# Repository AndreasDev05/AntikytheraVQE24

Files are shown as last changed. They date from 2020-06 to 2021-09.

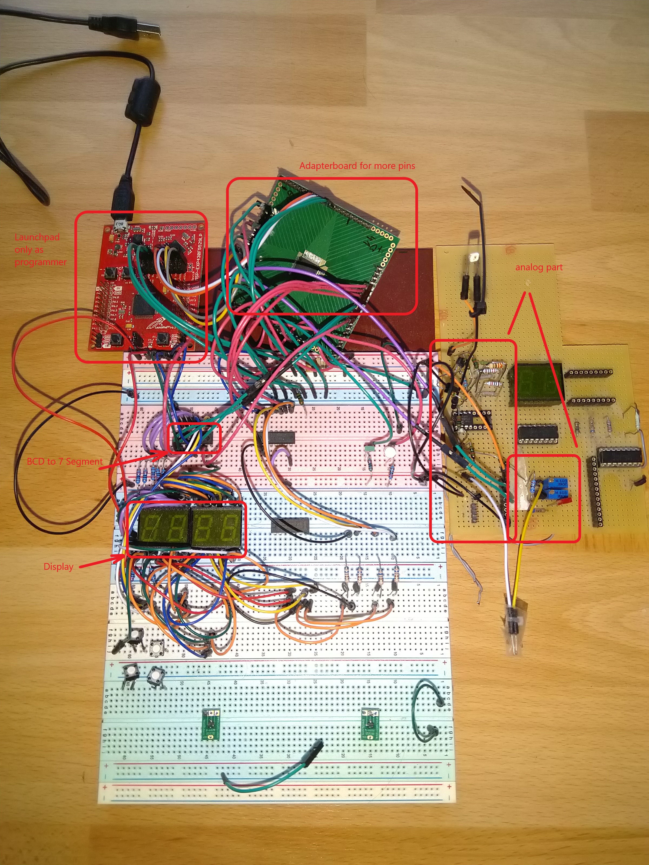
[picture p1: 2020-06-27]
Photos/Steckboard_202006.jpg

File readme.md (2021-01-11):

# Einleitung

Eine eigene Uhr zu bauen war ein Vorhaben das ich seit 35 Jahre habe. Damals bekam ich Anzeigen (VQE24) und einen entsprechenden Mikrocontroller geschenkt. Dieser war 2. Wahl und funktionierte auch nicht richtig. Ich bin nie über einen fliegenden Aufbau hinaus gekommen. Das möchte ich jetzt ändern und die Welt auch noch damit "bereichern". Bitte habe Geduld, vieles was ich hier tue, mache zum ersten Mal :wink: .

# Projektstatus:
**Software**

:construction: :construction_worker:

**Hardware (PCB)**

Die Entwicklung der Leiterplatte ist erst einmal fertig, ich habe die "Produktion" beauftragt :relaxed:.

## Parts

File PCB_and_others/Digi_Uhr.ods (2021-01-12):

Pos | Anzahl | Name | Wert | Gehäuse | SMD-Gehäuse
1 | 1 | AL1 | AL-16P01 | D18R7,62 | NO
2 | 1 | D400 | BAS16 | SOT23/3 | YES
3 | 5 | T500, T505, T506, T507, T401 | BSS138G | SOT-23/3 | YES
4 | 5 | T1, T501, T502, T503, T504 | BSS83P | SOT23/3 | YES
5 | 1 | K8 | Connector Power | Stiftleiste_1x03_G_2,54 | NO
6 | 1 | K3 | Connector Programmer | Stiftleiste_1x09_G_2,54 | NO
7 | 1 | RE400 | DIP 9051-D 5V | DIP_LOW_W/O | NO
8 | 1 | K300 | Einlöt-DC-Buchse 5.5/2.1mm | EINLÖT-DC-BUCHSE_2.5MM | NO
9 | 1 | T300 | IRFD9120 | DIL4 | NO
10 | 2 | J1, R500 | 0-OHM | 0603 | YES
11 | 1 | R2 | 1,4K | 0603 | YES
12 | 6 | R509, R510, R511, R512, R513, R530 | 10 | 0603 | YES
13 | 5 | R401, R406, R409, R419, R420, R302 | 100k | 0603 | YES
14 | 6 | C2, C13, C400, C402, C405, C410 | 100nF | 0603 | YES
15 | 6 | C4, C306, C401, C403, C509, C510 | 100nF | 1206 | YES
16 | 3 | C302, C303, C304 | 100µF | 2817_ELKO | YES
17 | 3 | R11, R422, R408 | 10K | 1206 | YES
18 | 1 | R405 | 10K | VISHAY_64W | NO
19 | 15 | R407, R411, R412, R413, R414, R415, R416, R505, R506, R507, R508, R514, R515, R516, R517 | 10k | 0603 | YES
20 | 9 | C406, C407, C409, C504, C505, C506, C507, C508, C511 | 10nF | 0603 | YES
21 | 2 | C14, C15 | 10pF | 0603 | YES
22 | 2 | C3, C12 | 10µF | 2412_ELKO | YES
23 | 1 | C301 | 10µF | 0805 | YES
24 | 1 | R300 | 19K1 | 0603 | YES
25 | 1 | R410 | 1k | 1206 | YES
26 | 1 | R4 | 1M | 0603 | YES
27 | 2 | C11, C408 | 1nF | 0603 | YES
28 | 5 | L300, L301, L302, L303, L304 | 1µH | Chip_Coil_4026 | YES
29 | 1 | L305 | 1µH | 1206-D | YES
30 | 1 | C305 | 2,2µF | 0805 | YES
31 | 1 | R520 | 220 | 1206 | YES
32 | 3 | C7, C8, C404 | 220nF | 0603 | YES
33 | 2 | C5, C6 | 22pF | 0603 | YES
34 | 5 | L500, L501, L502, L503, L504 | 22µH | SRN4018 Spule | YES
35 | 2 | R5, R6 | 27 | 0603 | YES
36 | 1 | Q1 | 32,768KHz | CFPX-6,7 | YES
37 | 9 | R3, R7, R8, R9, R10, R501, R502, R503, R504 | 33 | 1206 | YES
38 | 3 | R417, R418, R421 | 3M3 | 0805 | YES
39 | 2 | C1, C300 | 470nF | 0603 | YES
40 | 4 | C500, C501, C502, C503 | 470nF | 1206 | YES
41 | 1 | R1 | 47K | 0603 | YES
42 | 2 | R304, R404 | 4k7 | 0603 | YES
43 | 1 | R402 | 4M7 | 0603 | YES
44 | 1 | Q2 | 4MHz | HC49/US | NO
45 | 1 | R303 | 56K | 0603 | YES
46 | 2 | C9, C10 | 56pF | 0603 | YES
47 | 1 | R301 | 60K4 | 0603 | YES
48 | 1 | R400 | 68 | 0603 | YES
49 | 1 | IC2 | 74LS04 | SO14 | YES
50 | 11 | R518, R519, R521, R522, R523, R524, R525, R526, R527, R528, R529 | 82 | 1206 | YES
51 | 1 | R403 | 820k | 0603 | YES
52 | 1 | K1 | A-USBS-B | Assmann_A-USBS-B | NO
53 | 1 | K504 | K2X17_Buchse | 2X17_BUCHSE | NO
54 | 1 | D304 | LED_GRUEN | 0805-D | YES
55 | 2 | D500, D501 | LED_GRUEN_3MM | LED_3MM_GRÜN | NO
56 | 1 | D502 | LED_GRUEN_rechtek | LED_2X5_Grün | NO
57 | 2 | D302, D303 | LED_ROT | 0603-D | YES
58 | 1 | IC402 | LM334Z | TO92(1) | NO
59 | 1 | IC403 | LM4041DIM3-1.2 | SOT23/3 | YES
60 | 1 | IC404 | LP2951 CS33 | SO8_SOT96-1 | YES
61 | 1 | U300 | MAX17620ATA+ | 21-0168E_T822-3_MXM | NO
62 | 1 | IC400, IC405 | MCP602-I/SN | SO8_SOT96-1 | YES
63 | 1 | IC1 | MSP430F5529 | LQFP80_SOT315-1 | YES
64 | 1 | D1 | PRTR5V0U2X | SOT143B | YES
65 | 1 | IC401 | PT100 | STIFTLEISTE_1X02_G_2,54 | NO
66 | 1 | T400 | SFH320-3 | STIFTLEISTE_1X02_G_2,54 | NO
67 | 2 | D300, D301 | SKL13B | DO-214AA(SMB) | YES
68 | 1 | D503 | SMD 0805 gelb | 0805-D | YES
69 | 1 | IC500 | SN7447N | DIL16 | NO
70 | 1 | IC501 | SN74LS47 | SO16 | YES
71 | 1 | X300 | Stützbatterie | BATTERIE_HALTER_VERT | NO
72 | 1 | SW504 | Switch center | 1.14.100.501/0000_RAF (ANDI) | NO
73 | 1 | SW500 | Switch down | 1.14.100.501/0000_RAF (ANDI) | NO
74 | 1 | SW502 | Switch left | 1.14.100.501/0000_RAF (ANDI) | NO
75 | 1 | SW503 | Switch rigth | 1.14.100.501/0000_RAF (ANDI) | NO
76 | 1 | SW501 | Switch up | 1.14.100.501/0000_RAF (ANDI) | NO
77 | 1 | S505 | Taster_Kurzhub | STIFTLEISTE_1X02_G_2,54 | NO
78 | 2 | Display500, Display501 | TLG325 | DX52-11 | NO
79 | 1 | K2 | Verbinder Frontplatte | Stiftleiste_2x17_G_2,54 | NO
 | 178

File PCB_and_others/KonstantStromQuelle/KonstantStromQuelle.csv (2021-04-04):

Reference | Quantity | Value | Footprint | Datasheet
C1 C2 | 2 | 120n | Capacitor_SMD:C_0805_2012Metric_Pad1.15x1.40mm_HandSolder | ~
J1 | 1 | Konstantstromquelle | Package_TO_SOT_THT:TO-92L_Inline_Wide | ~
J2 | 1 | +5V | Connector_Pin:Pin_D0.9mm_L10.0mm_W2.4mm_FlatFork | ~
J3 | 1 | Halte-Pin | Connector_Pin:Pin_D0.9mm_L10.0mm_W2.4mm_FlatFork | ~
Q1 | 1 | BSS138 | Package_TO_SOT_SMD:SOT-23 | https://www.fairchildsemi.com/datasheets/BS/BSS138.pdf
R1 | 1 | 10k Reserve | Resistor_SMD:R_1206_3216Metric_Pad1.42x1.75mm_HandSolder | ~
R2 | 1 | 10k | Resistor_SMD:R_1206_3216Metric_Pad1.42x1.75mm_HandSolder | ~
R3 | 1 | 1k | Resistor_SMD:R_1206_3216Metric_Pad1.42x1.75mm_HandSolder | ~
RV1 | 1 | 10k | Potentiometer_THT:Potentiometer_Bourns_3296W_Vertical | ~
U1 | 1 | LM4041DIM3-1.2 | Package_TO_SOT_SMD:SOT-23 | http://www.ti.com/lit/ds/symlink/lm4041-n.pdf
U2 | 1 | SGM8521 | Package_SO:SO-8_3.9x4.9mm_P1.27mm | I:\User_Daten\andi_dir\Dokumente\Technik\Digi-Uhr\SGM8521.pdf

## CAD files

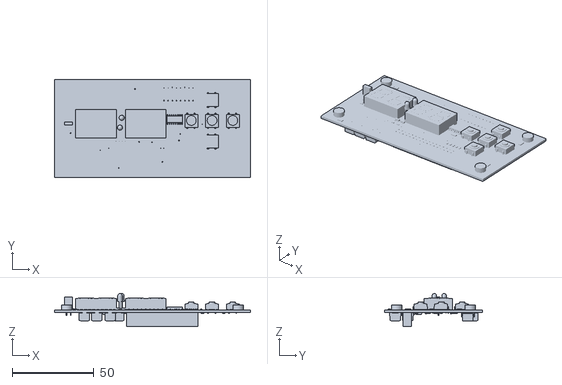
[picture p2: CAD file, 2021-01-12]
PCB_and_others/Digi_Uhr_Front.OBJ
120.0 x 60.0 x 20.2

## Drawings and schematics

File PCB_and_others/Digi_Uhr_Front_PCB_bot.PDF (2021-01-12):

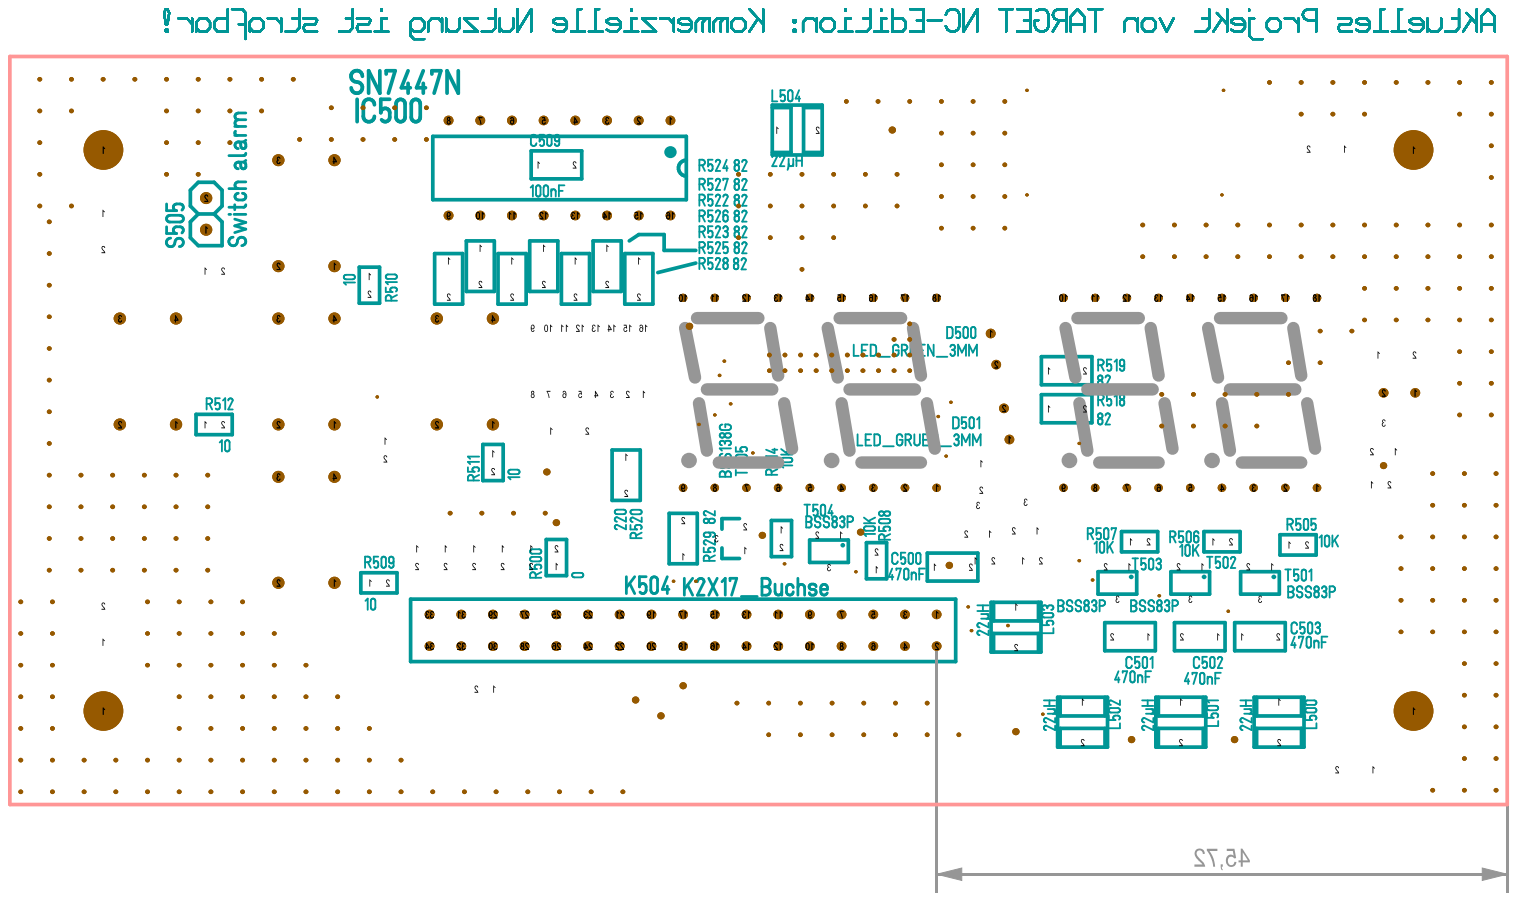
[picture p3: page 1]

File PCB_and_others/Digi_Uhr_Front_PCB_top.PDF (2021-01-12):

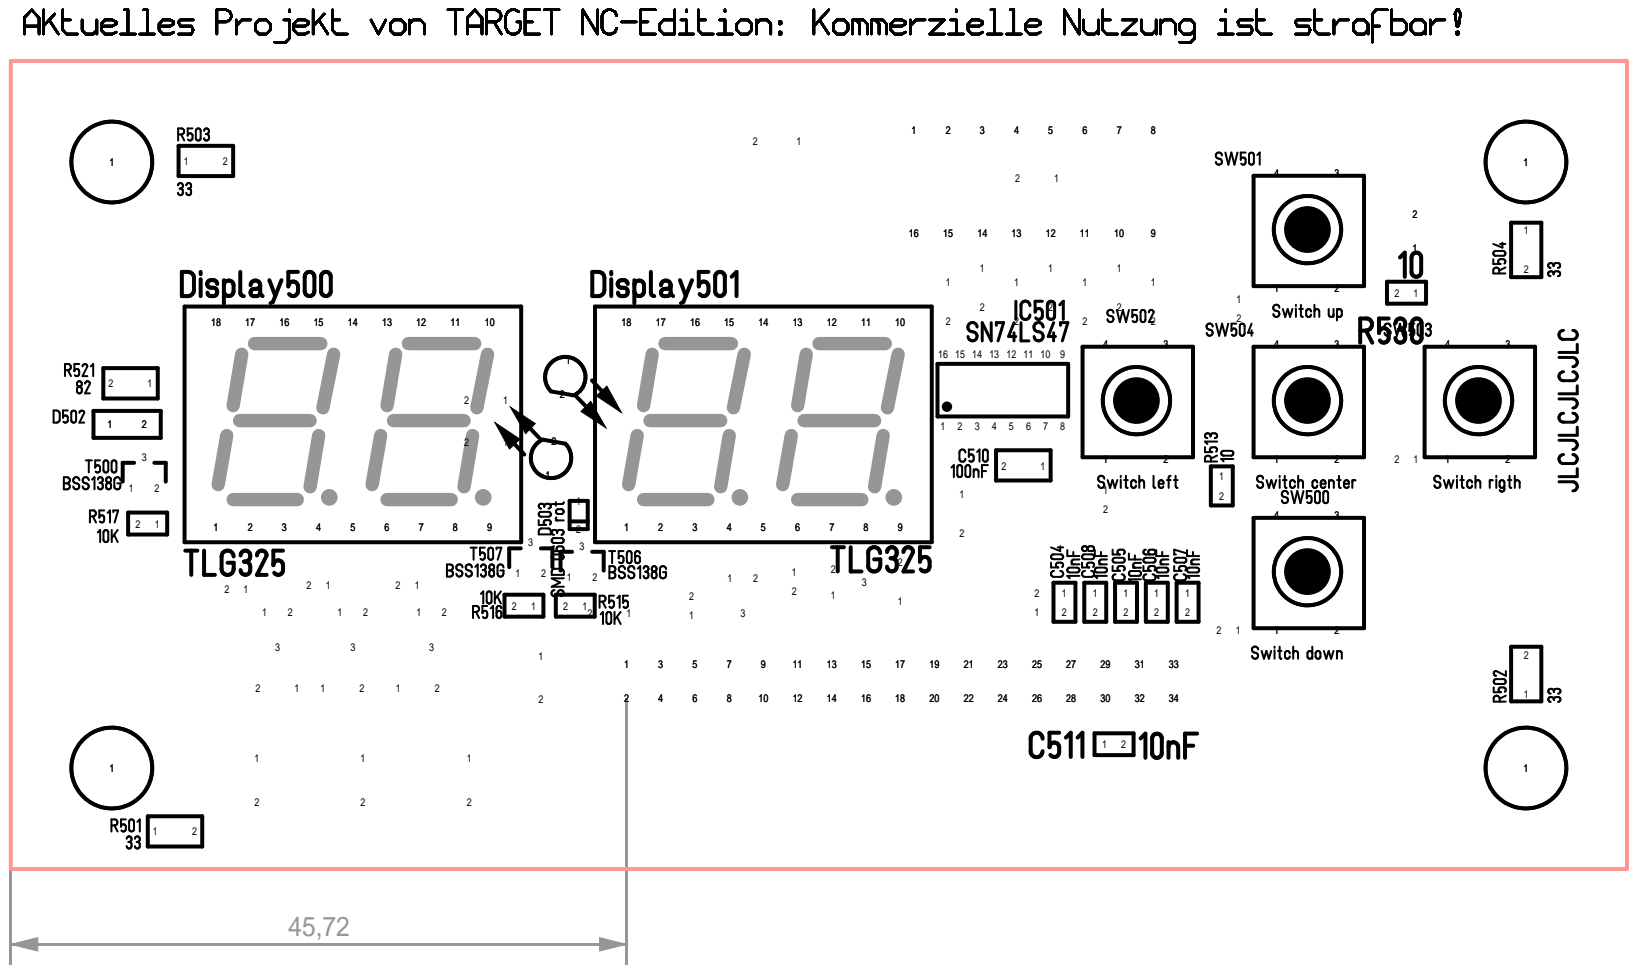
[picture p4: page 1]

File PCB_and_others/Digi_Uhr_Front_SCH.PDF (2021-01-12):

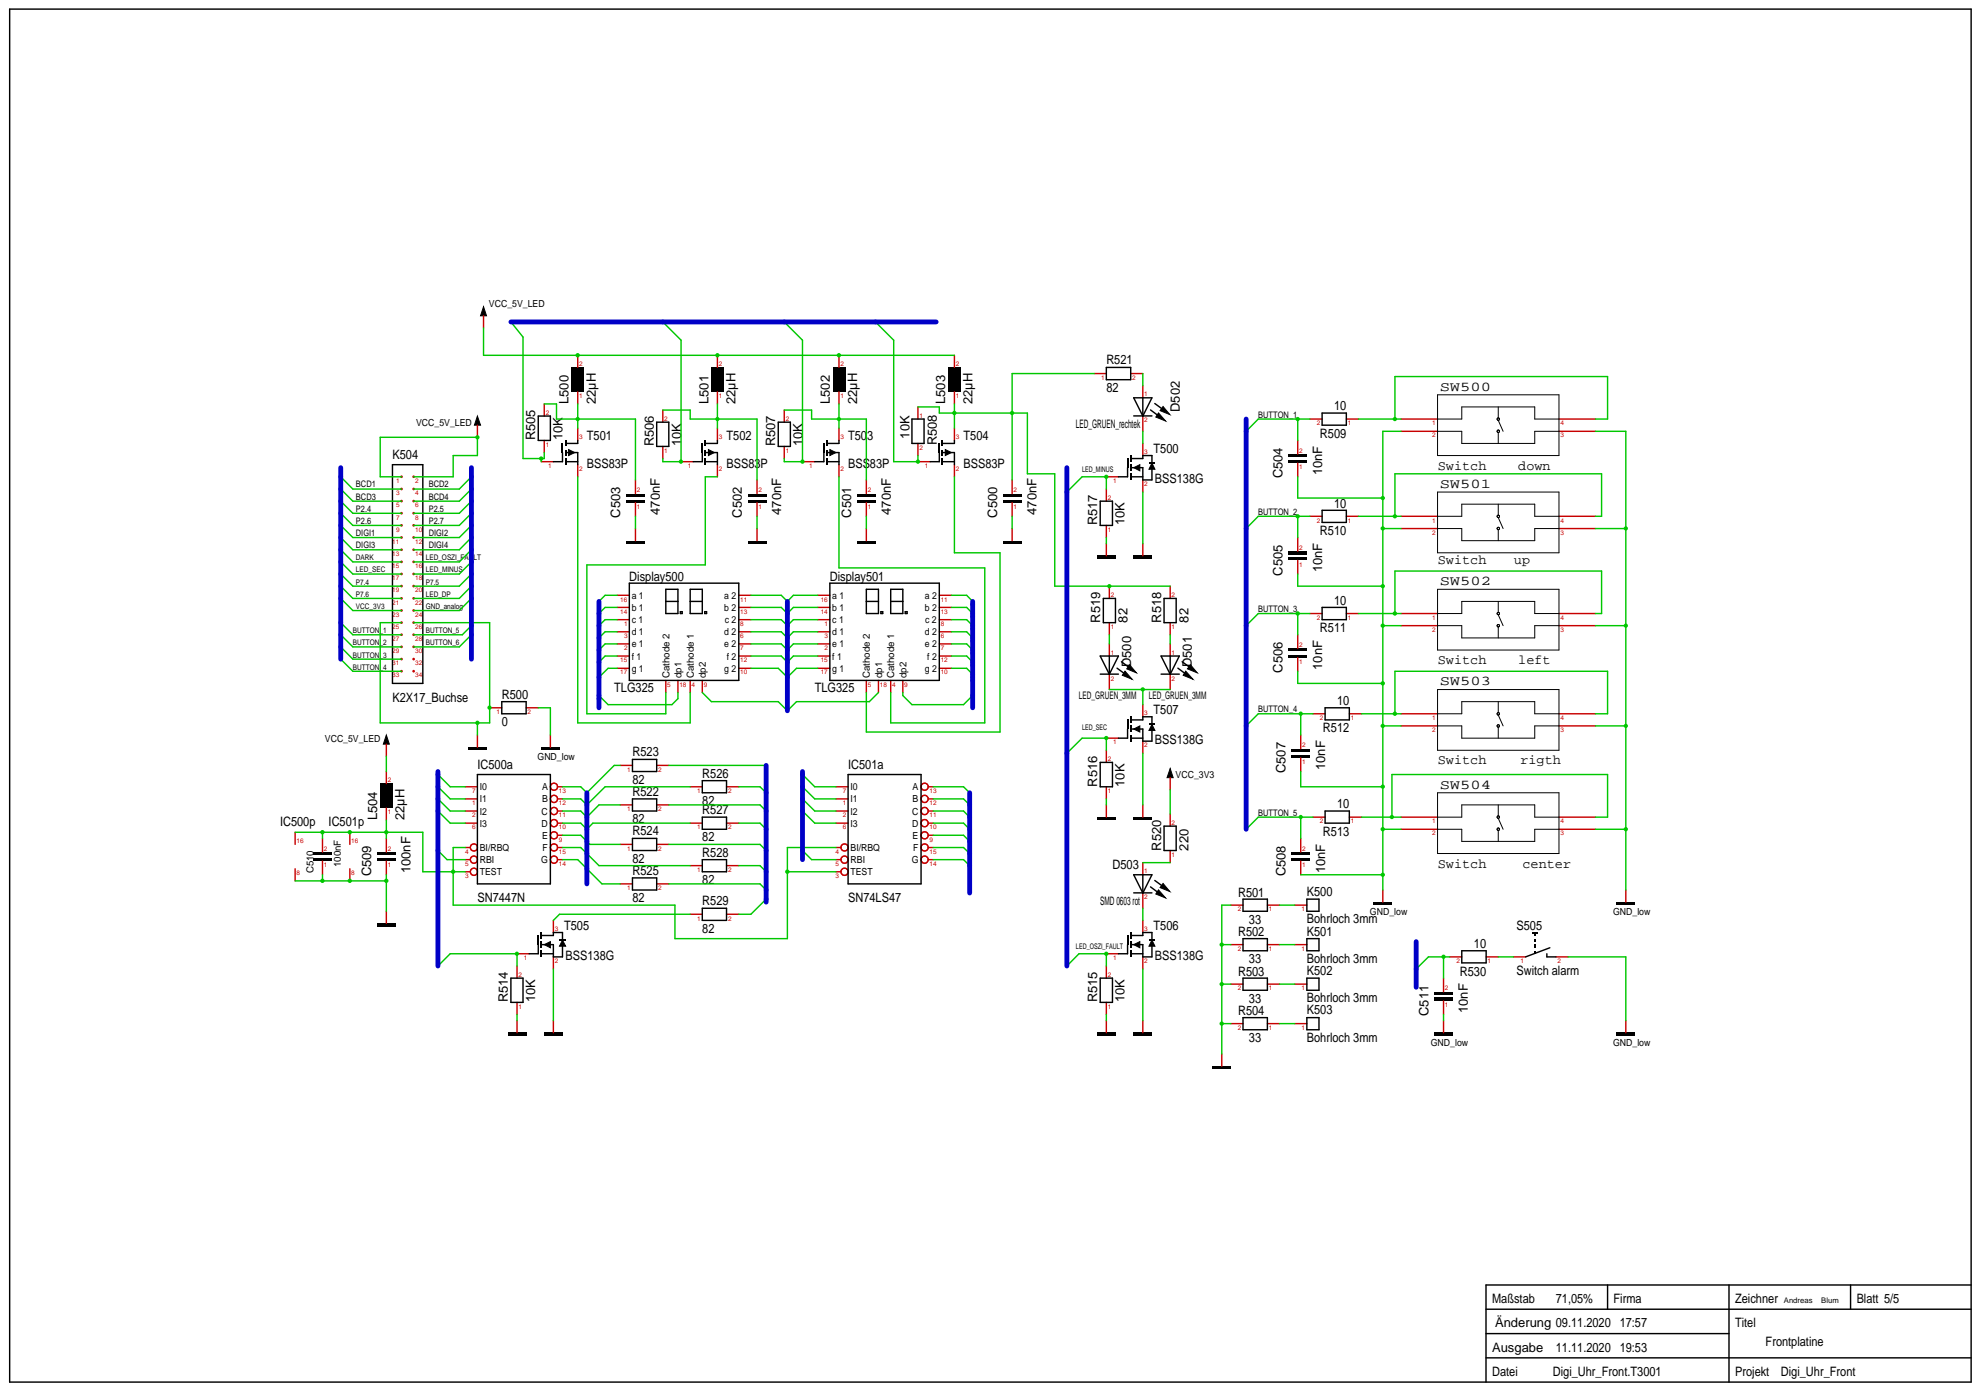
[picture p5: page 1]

Maßstab 71,05% | Firma | Zeichner Andreas Blum | Blatt 5/5
Änderung 09.11.2020 17:57 | | Titel Frontplatine

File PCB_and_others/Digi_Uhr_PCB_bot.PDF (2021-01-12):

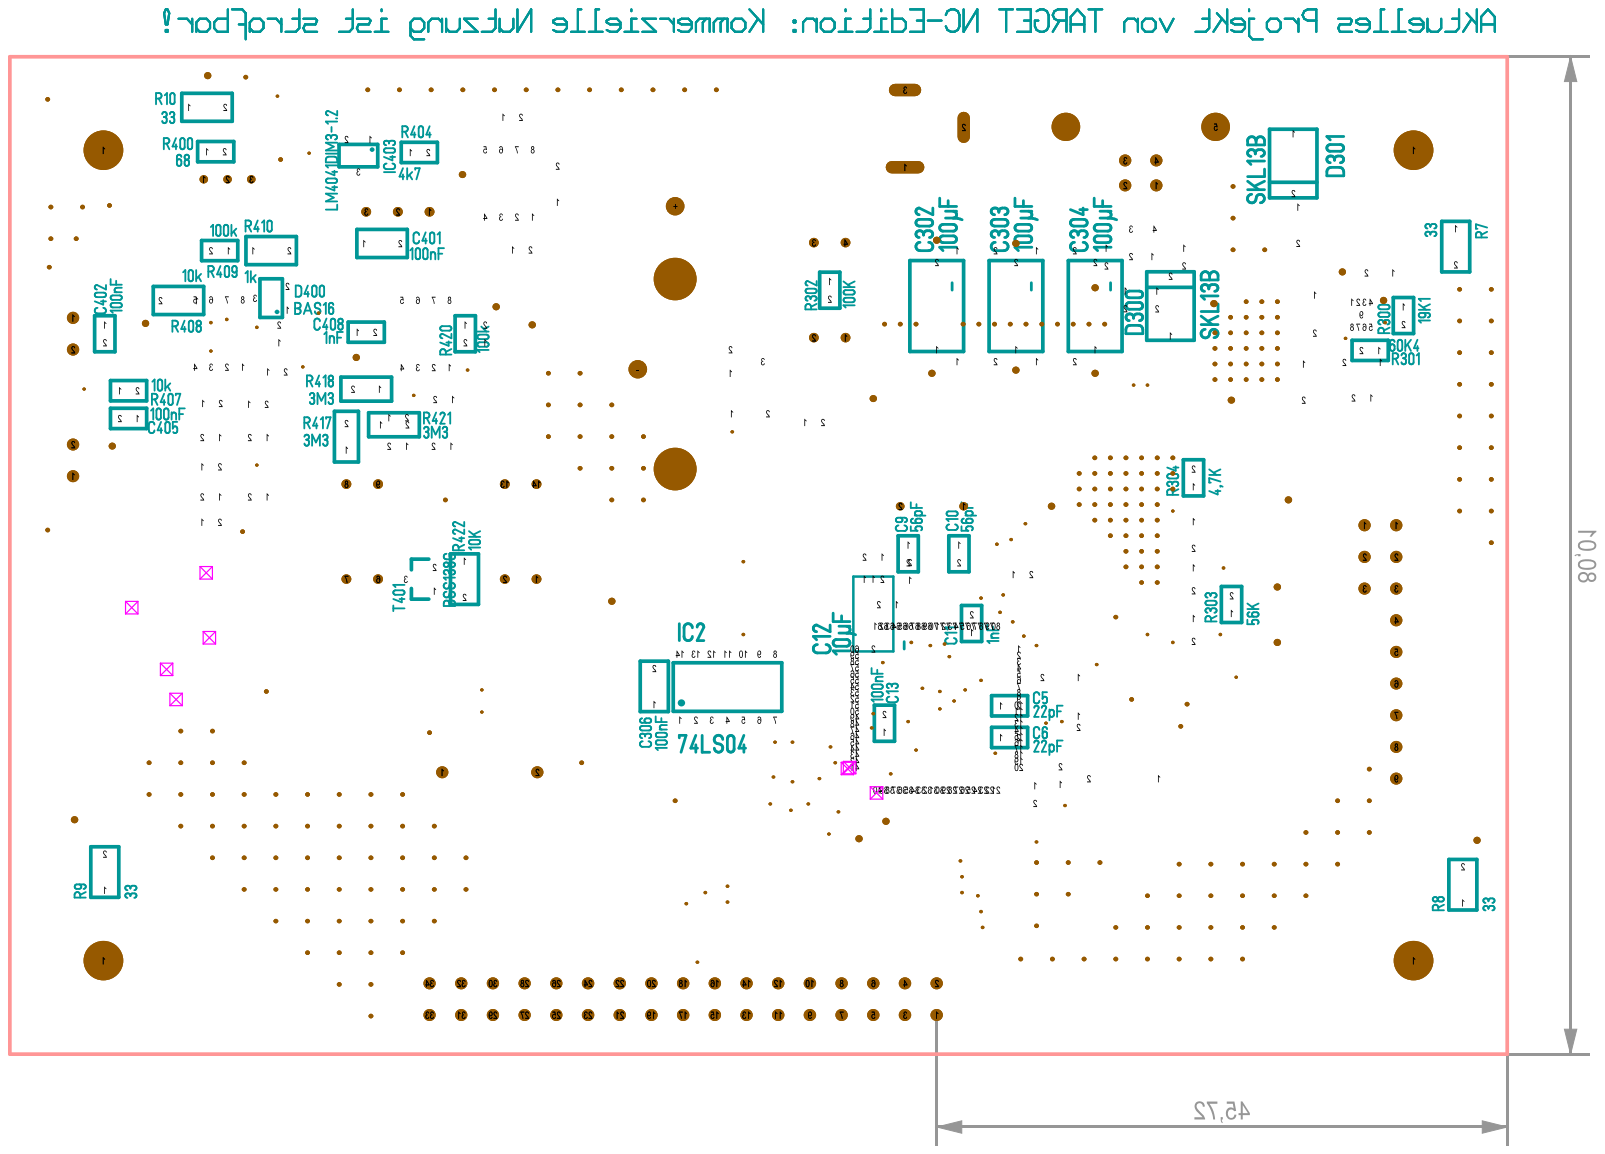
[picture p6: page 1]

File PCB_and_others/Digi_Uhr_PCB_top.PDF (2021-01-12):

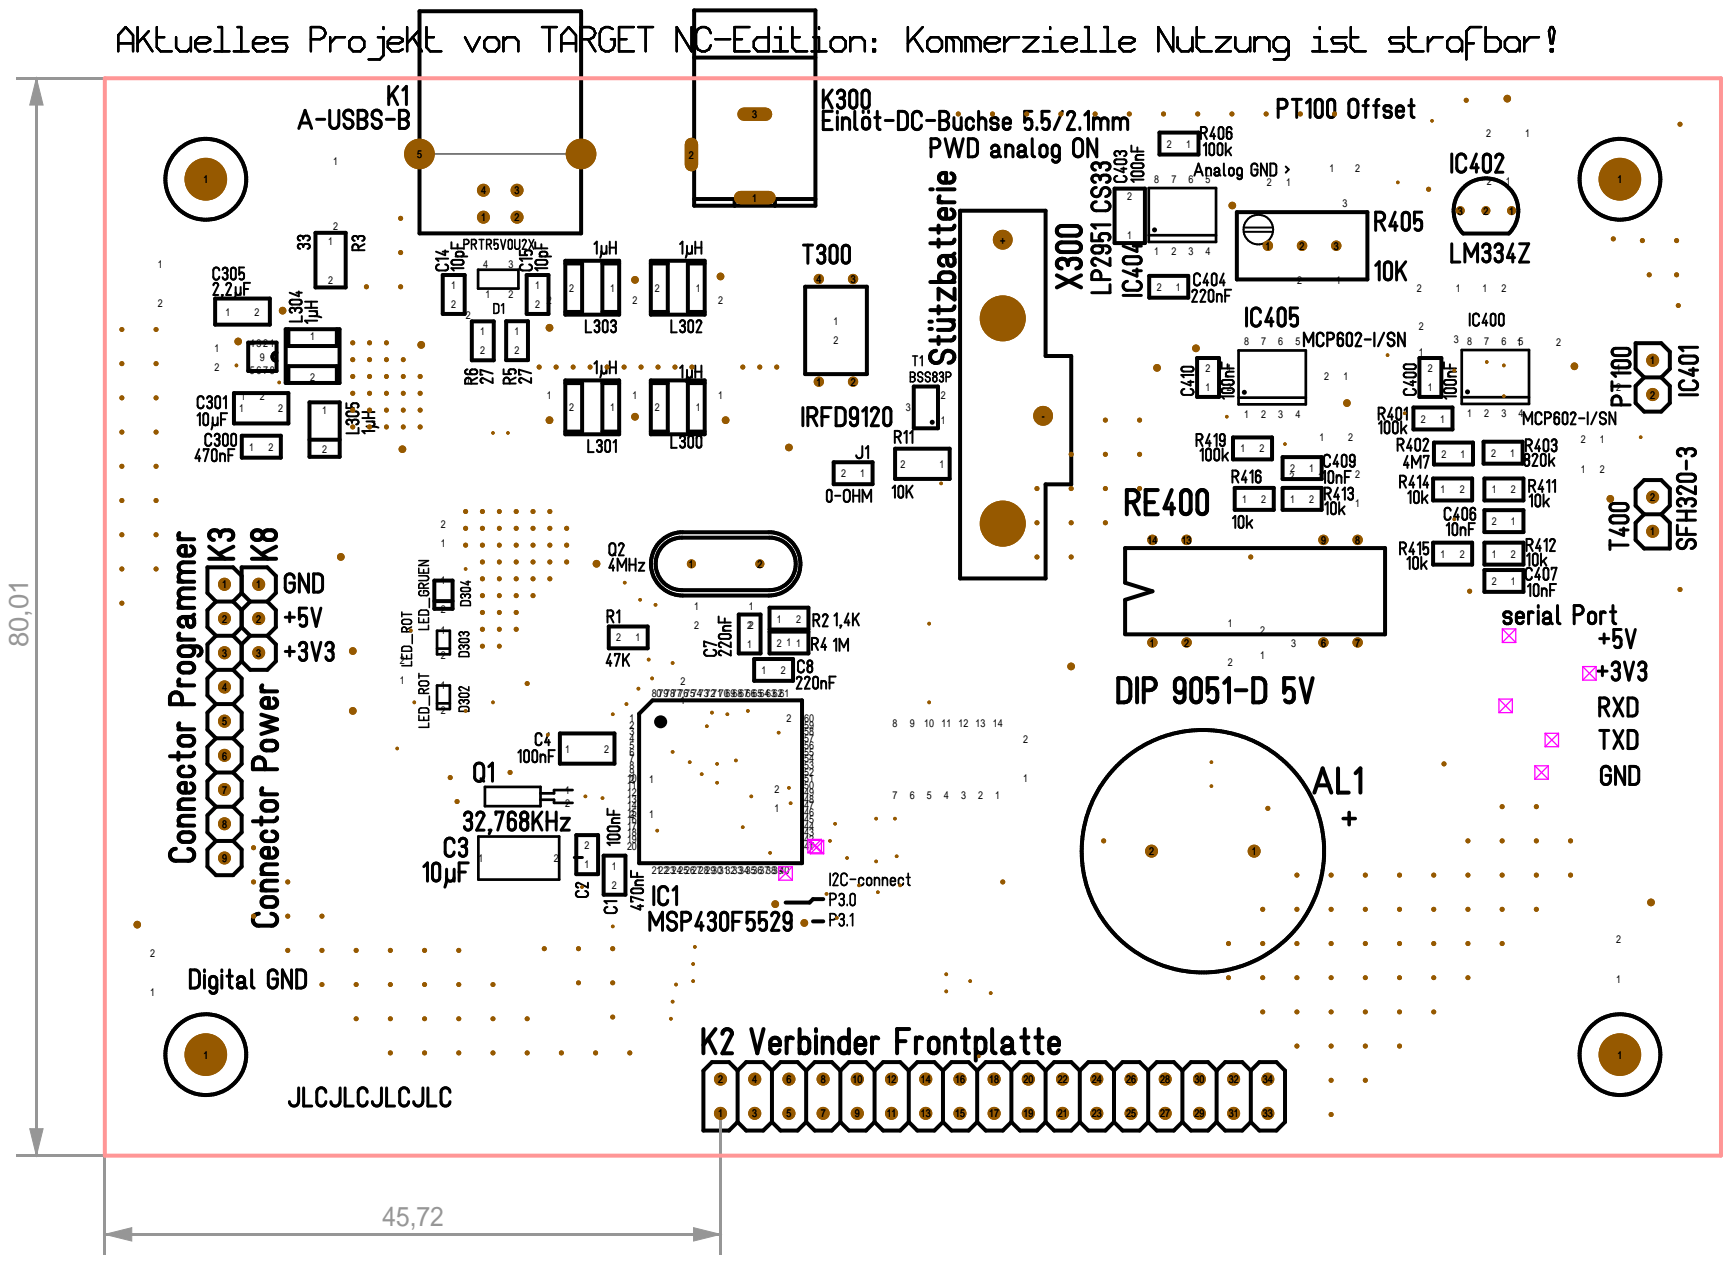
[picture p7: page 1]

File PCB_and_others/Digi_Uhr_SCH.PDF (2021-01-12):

### IC2a

K2

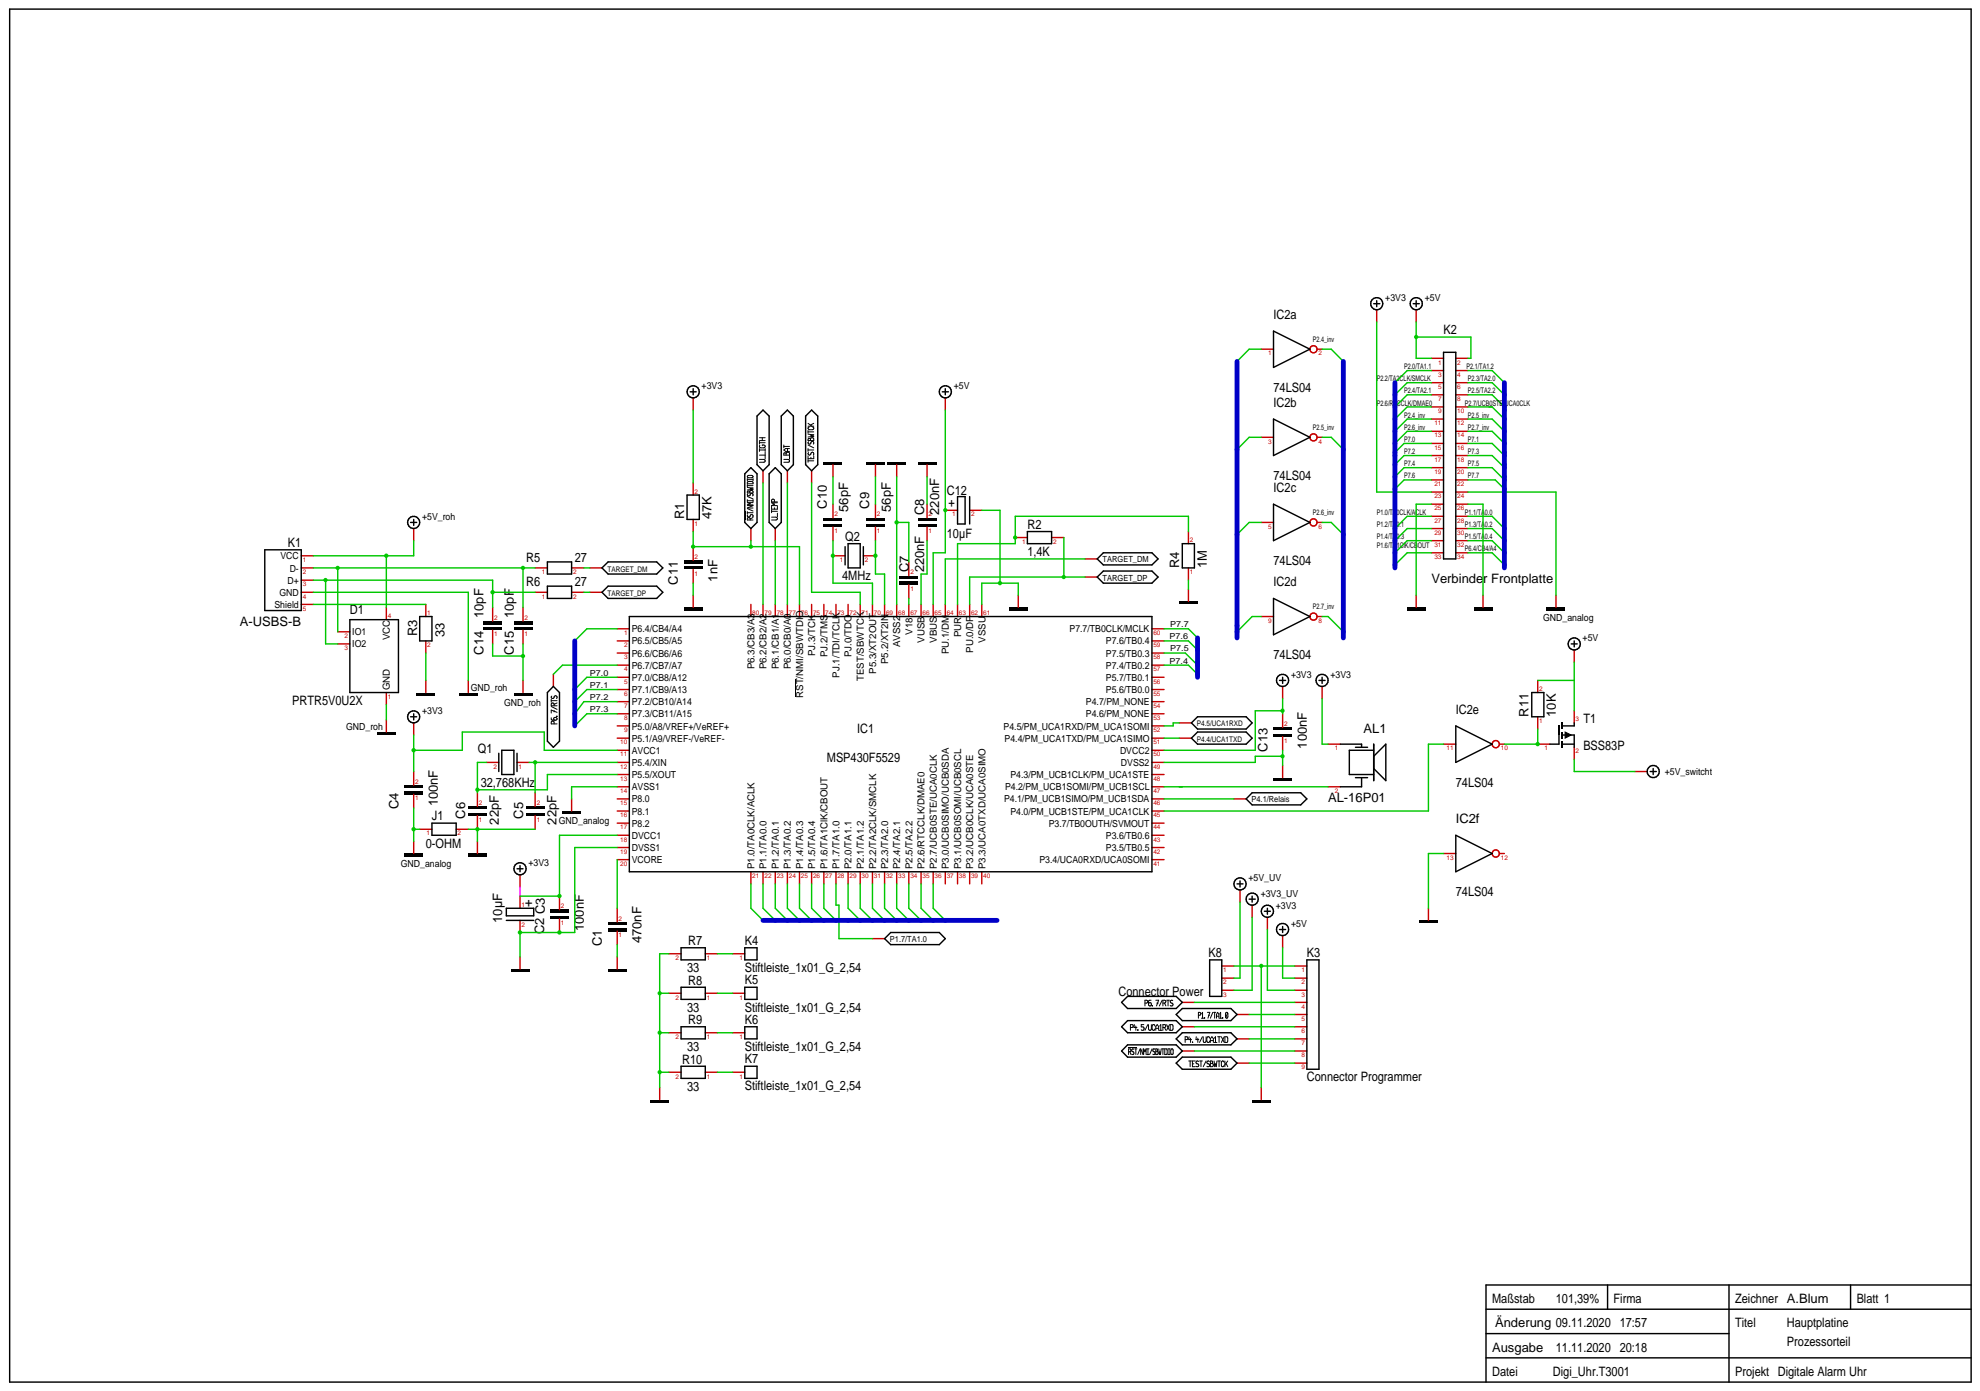
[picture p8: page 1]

Maßstab 101,39% | Firma | Zeichner A.Blum | Blatt 1
Änderung 09.11.2020 17:57 | | Titel Hauptplatine Prozessorteil

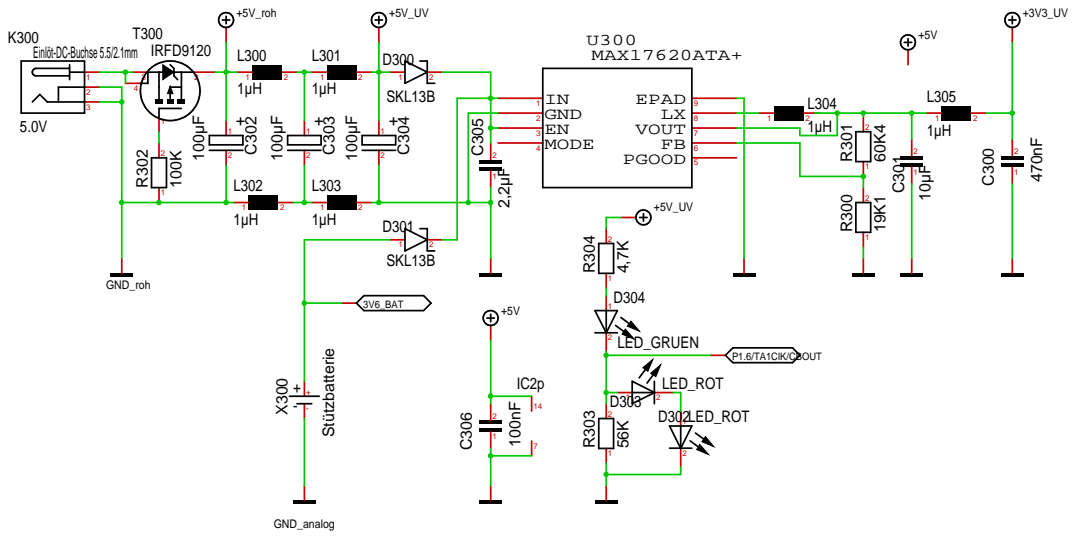
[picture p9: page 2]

Maßstab 71,05% | Firma | Zeichner A.Blum | Blatt 2

Stromversorgung

## 3V3_analog

100k

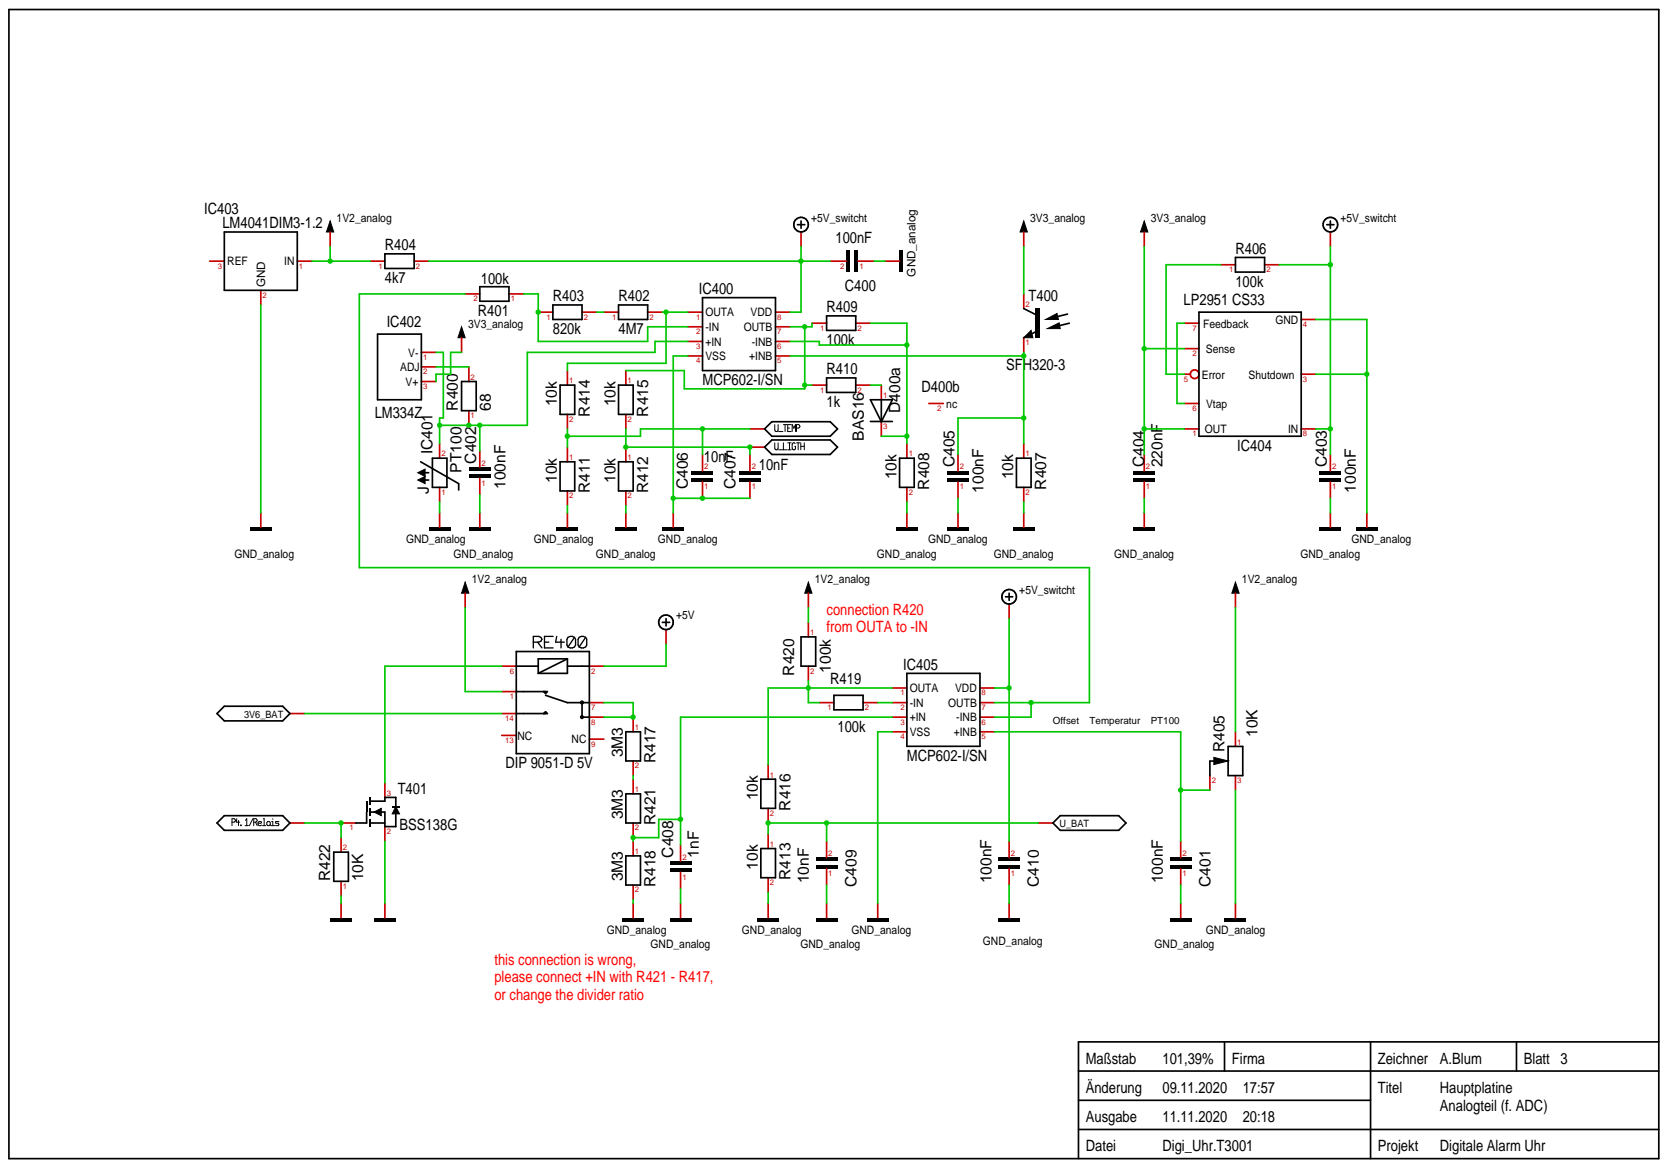
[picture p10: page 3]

this connection is wrong,
please connect +IN with R421 - R417,
or change the divider ratio

Maßstab 101,39% | Firma | Zeichner A.Blum | Blatt 3

Analogteil (f. ADC)

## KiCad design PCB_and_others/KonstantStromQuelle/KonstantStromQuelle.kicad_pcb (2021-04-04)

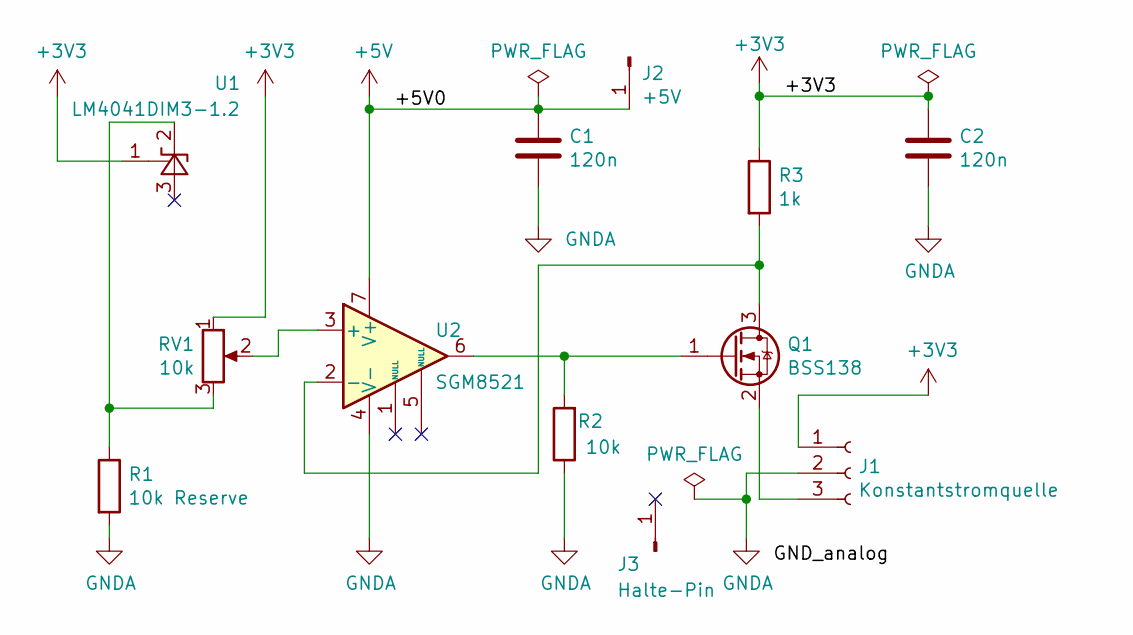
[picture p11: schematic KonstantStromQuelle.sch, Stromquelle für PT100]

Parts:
C1, C2: 120n; C_0805_2012Metric_Pad1.15x1.40mm_HandSolder
J1: Konstantstromquelle; TO-92L_Inline_Wide
J2: +5V; Pin_D0.9mm_L10.0mm_W2.4mm_FlatFork
J3: Halte-Pin; Pin_D0.9mm_L10.0mm_W2.4mm_FlatFork
Q1: BSS138; SOT-23
R1: 10k Reserve; R_1206_3216Metric_Pad1.42x1.75mm_HandSolder
R2: 10k; R_1206_3216Metric_Pad1.42x1.75mm_HandSolder
R3: 1k; R_1206_3216Metric_Pad1.42x1.75mm_HandSolder
RV1: 10k; Potentiometer_Bourns_3296W_Vertical
U1: LM4041DIM3-1.2; SOT-23
U2: SGM8521; SO-8_3.9x4.9mm_P1.27mm

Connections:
+3V3: C2.1, J1.1, R3.1, RV1.1, U1.1 (FB)
+5V: C1.1, J2.1, U2.7 (V+)
GNDA: C1.2, C2.2, J1.2, R1.2, R2.1, U2.4 (V-)
unnamed: J1.3, Q1.2 (S)
unnamed: Q1.1 (G), R2.2, U2.6
unnamed: Q1.3 (D), R3.2, U2.2 (-)
unnamed: R1.1, RV1.3, U1.2 (K)
unnamed: RV1.2, U2.3 (+)

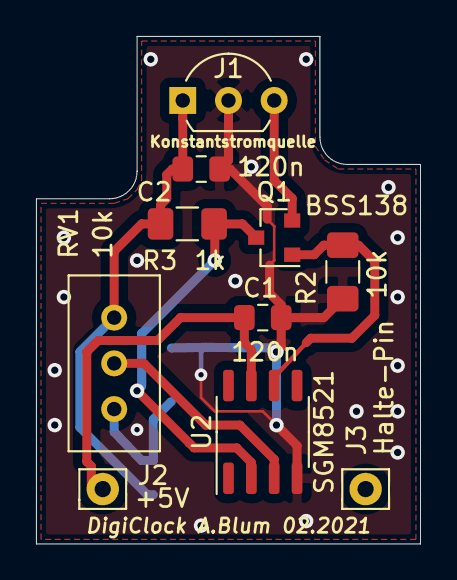
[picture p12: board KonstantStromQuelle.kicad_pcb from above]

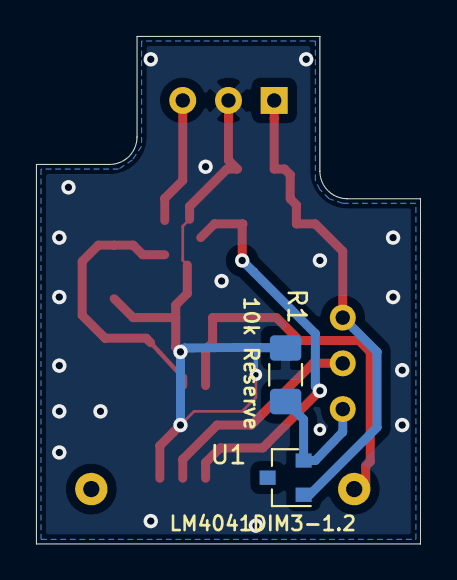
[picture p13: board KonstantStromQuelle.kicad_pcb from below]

Board: 2 copper layers, 21.3 x 28.2 mm, 12 parts (2 on the bottom side), 8 nets.

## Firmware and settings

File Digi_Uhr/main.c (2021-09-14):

#include <stdbool.h>
#include <stdint.h>
#include <string.h>
#include <msp430.h>
#include <msp430f5529.h>
// !!!! Hardwareversion of PCB
#define HW_Ver1_0
//
#include <digi_clock.h>
#include <digi_clock_isr.h>
#include <digi_clock_flash.h>
#include <digi_clock_btn_menu.h>
#include <digi_clock_alarm_fkt.h>
#include <digi_clock_fkt.h>


// Variables global clock management

// Variablen in den Interruptfkt. -----
    volatile bool is_pwr_good = true;
    volatile uint8_t is_sec,is_msec,is_msec2, is_100ms, is_100ms2, is_300ms = 0;
    uint8_t old_min, old_hour, old_day = 1;

    // Which value will be displayed
    volatile enum EVE_con_typ eve_condition = view_sec_and_min;

// Variables for display management
    // to fast find the pin-quartet on display-port
    unsigned const int disp_pos[2] = {0x8040,0x2010};
    // display-memory position and BCD-number
    volatile uint8_t disp_out[4] = {0x40,0x81,0x12,0x24};
    // display-memory decimal point and other LEDs
    volatile uint8_t disp_point = DIGT_PNT1, disp_point_blink;
    // for fast overlay-functions on the display-memory
    volatile uint16_t  *disp_out_int = disp_out;
    volatile void *disp_out_int_ptr = &disp_out;
    // to reduce flicker save the display in this memory
    volatile uint8_t disp_out_buf[4];
    volatile uint16_t  *disp_out_buf_int = &disp_out_buf;
    volatile void *disp_out_buf_int_ptr = &disp_out_buf;
    // pointer to the active display-memory
    volatile uint8_t *disp_out_point = disp_out;
    volatile uint8_t disp_count = 0;
    // the brightness of the display: it is recommended to use values between 10 and "TIME_PERIOD_DIGT"-10.
    volatile uint16_t  disp_brightness = 10;  // brightness

// Variables for button-logic
    volatile uint8_t btn_is_int_set;
    uint8_t    btn_in_work = 0;
    uint16_t   btn_counter[6] = {0,0,0,0,0,0};
    uint8_t    btn_event[6] = {0,0,0,0,0,0};
    void const *btn_event_int_ptr = (uint16_t *)&btn_event[0]; // later used 16 bit integer values are used to accelerate the comparison.
    const uint8_t btn_adaptation[] = {BUTTON_1,BUTTON_2,BUTTON_3,BUTTON_4,BUTTON_5,BUTTON_6};

    uint8_t menu_stop_timer = 0;

// Variables for alarm-logic
    uint8_t     alarm_start_flags = 0;
    const uint8_t alarm_intv1[] = {1,1,9};  // Stepcounter, ON-Inv, OFF-Inv, ... in 0,1sec
    const uint8_t alarm_intv2[] = {3,1,3,1,7};
    const uint8_t alarm_intv3[] = {3,1,1,1,5};
    const uint8_t alarm_intvT[] = {3,6,11,2,9,1,4,17,1,3,1,4,5,1,1,1};
/*                                 |      | | |
                                   |      | | Count of beeper ON in 100msec
                                   |      | Count of beeper OFF in 100msec
                                   |      Count of Bytes for the melodies (minus 1)
                                   Byte 1-3 Offset too melodies */
    struct alarm_set alarm_data[5];
    uint8_t alarm_order[5];

// Variables for FlashWriting
    enum FLASH_write_data flash_which_data;

// Variables for ADC12
    volatile uint16_t adc_out_raw[8];
    uint16_t adc_out_bright_contr, adc_out_bright_f_disp, adc_out_batt_f_contr,
        adc_out_batt_f_disp, adc_out_batt_f_disp_raw, adc_out_temp_cpu_f_disp_raw,
        adc_out_temp_out_f_disp_raw;
    int16_t adc_out_temp_cpu_f_disp, adc_out_temp_out_f_disp;
    volatile bool adc_conv_ready;
    uint8_t  adc_out_ready = 0; // Bitarray that signalizes witch ADC-channel is ready - named bits in the header
    uint8_t  adc_power_count = 0; // if i switch on the power for the analog circuit
    uint16_t temp_s_sum;
    int32_t  temp_cpu_coefficient, temp_out_coefficient, batt_coefficient; // precalculated factor for CPU-temperature measurement
    int32_t  calcu_extension;

/**
 * main.c
 */
int main(void)
{

    volatile uint8_t temp_byte = 0;

//    btn_event_int_ptr = (uint16_t *)&btn_event[0];

//////////// Initialize CPU function
    InitializeCPU();
// Initialize UCS
    Initialize_UCS_and_Crystals();
// Initialize the real time clock
    InitializeRTC();
// Initialize ADC12
    InitializeADC12();

// Initialize PortPins
    InitializePins();

// Initialize Timer A0 & A1
    InitializeTimerA();

// main loop

    while (1)
    {
        if (is_pwr_good)  // USB-supply is ready
        {
            if (is_sec != 0)
            {
                is_sec--;
//                SIGNALS_OUT    ^= DARK;                            // Toggle P7.3
//                CONTROL_OUT ^= TURNON_RELAY;
                switch (eve_condition)
                {
                case view_temp_out:
//                ADC_scheduler(measure_bright_f_contr);
                    ADC_scheduler(measure_temp_out_f_disp);
                    break;
                case view_temp_cpu:
                    ADC_scheduler(measure_temp_cpu_f_disp);
                    break;
                case view_batt:
                    ADC_scheduler(measure_batt_f_disp);
                    break;
                case view_bright:
                    ADC_scheduler(measure_bright_f_disp);
                    break;
                }
                if (RTCMIN != old_min)
                {
                    old_min = RTCMIN;
//                    alarm_start_flags |= ALARM_BEEP;
/*                    if (RTCMIN == 0x23) alarm_start_flags |= ALARM_LEV02;
                    if (RTCMIN == 0x24)
                    {
                        alarm_start_flags &= ~ALARM_LEV02;
                        alarm_start_flags |= ALARM_STOP;
                    }   */
                    if (RTCHOUR != old_hour)
                    {
                        old_hour = RTCHOUR;
                        if (RTCDAY != old_day)
                        {

                        }
                    }
                }
                if (menu_stop_timer != 0)
                {
                    menu_stop_timer--;
                    if (menu_stop_timer == 0) clock_event_to_menu(MENU_STOP_FLAG);
                }
                //                StartADCmeasurements(measurement_bright);
//                CONTROL_OUT ^= AL1;
            }
//-----///////////////
            if (is_100ms != 0)  // is derived from 4MHz clock
            {
                is_100ms--;
                if (adc_power_count != 0)
                {
                    ADC_scheduler(status_adc_pwr_go_on);
                }
                if (adc_out_ready & TEMP_CPU_F_DISP_READY)
                {
//                    i = CALADC12_15V_30C;
                    __no_operation();
/*                    calcu_extension = (int32_t)((int32_t)adc_out_temp_cpu_f_disp_raw - (int32_t)CALADC12_15V_30C);
                    calcu_extension *= temp_cpu_coefficient;
                    calcu_extension += 30000;
                    calcu_extension /= 100;
                    adc_out_temp_cpu_f_disp = calcu_extension; */
/*                            (uint16_t) (((int32_t) () * temp_cpu_coefficient
                                    + 30000) / 100); */
                    calcu_temp_cpu_to_int();
                    GenerateDispOut();
                    adc_out_ready &= ~TEMP_CPU_F_DISP_READY;
                }
                if (adc_out_ready & TEMP_OUT_F_DISP_READY)
                {
                    calcu_temp_out_to_int();
                    GenerateDispOut();
                    adc_out_ready &= ~TEMP_OUT_F_DISP_READY;
                }
                if (adc_out_ready & BATT_F_DISP_READY)
                {
                    calcu_batt_to_int();
                    GenerateDispOut();
                    adc_out_ready &= ~BATT_F_DISP_READY;
                }
                if (adc_out_ready & BRIGHT_F_DISP_READY)
                {
                    GenerateDispOut();
                    adc_out_ready &= ~BRIGHT_F_DISP_READY;
                }
            } // if (is_100ms != 0)
//-----///////////////
            if (is_100ms2 != 0)  // is derived from 32kHz clock
            {
                is_100ms2--;
                btn_to_event();
                if ((alarm_start_flags & ALARM_BEEP) != 0)
                    AlarmBeep();
                if (alarm_start_flags & (ALARM_STOP | ALARM_LEV01 | ALARM_LEV02 | ALARM_LEV03 | ALARM_LEV04))
                    AlarmBell();
//                if (my_alarm_flags.alarm_on == 1) AlarmBell();

            } // if (is_100ms2 != 0)
//-----///////////////
            if (is_300ms != 0)
            {
                switch (eve_condition)
                {
                case normal:
                    GenerateDispOut();
                    break;
                case view_sec_and_min:
                    GenerateDispOut();
                    break;
                }
                is_300ms--;
                disp_brightness += 10;
                if (disp_brightness > TIME_PERIOD_DIGT - 10)
                    disp_brightness = 5;
            }
//            for (i = 4000; i > 0; i--)
            ;     // delay
//------///////////////
            if (adc_conv_ready)
            {
                ADC_scheduler(status_adc_ready);
                /*                adc_conv_ready = false;
                 temp_s_sum = 0;
                 for (i = 8; i > 0; i--)
                 {
                 temp_s_sum += adc_out_raw[i - 1];
                 }
                 temp_s_sum >>= 3; */
            }
/*
 * Button-events
 */
            if ((*(uint16_t *) btn_event_int_ptr)
                    || (*(uint16_t *) (btn_event_int_ptr + sizeof(uint16_t)))
                    || (*(uint16_t *) (btn_event_int_ptr + 2 * sizeof(uint16_t))))
            {
                clock_event_to_menu(MENU_WHATEVER_FLAG);
                GenerateDispOut();
            }
            __no_operation();                         // For debugger
        }
        else  // is_pwr_good
        {
            // batt. operated
        }
    }
}

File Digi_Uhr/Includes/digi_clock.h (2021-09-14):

/*
 * digi_clock.h
 *
 *  Created on: 27.04.2020
 *      Author: andi
 */
#include <stdbool.h>
#include <msp430.h>
//#include <msp430f2229.h>

#ifndef INCLUDES_DIGI_CLOCK_H_
#define INCLUDES_DIGI_CLOCK_H_

#define     BUTTON_OUT            P1OUT
#define     BUTTON_DIR            P1DIR
#define     BUTTON_IN             P1IN
#define     BUTTON_IE             P1IE
#define     BUTTON_IES            P1IES
#define     BUTTON_IFG            P1IFG
#define     BUTTON_REN            P1REN

/*/ #ifdef HW_Ver1_2
#define     BUTTON_1              BIT0      // Switch down
#define     BUTTON_2              BIT1      // Switch up
#define     BUTTON_3              BIT2      // Switch left
#define     BUTTON_4              BIT3      // Switch right
#define     BUTTON_5              BIT4      // Menu
#define     BUTTON_6              BIT5      // Alarm off
#endif */

// #ifdef HW_Ver1_0
#define     BUTTON_1              BIT0      // Switch down
#define     BUTTON_2              BIT2      // Switch up
#define     BUTTON_3              BIT4      // Switch left
#define     BUTTON_4              BIT6      // Switch right
#define     BUTTON_5              BIT1      // Menu
#define     BUTTON_6              BIT3      // Alarm off
//#endif

#define     BUTTON_down           BIT0      // Switch down
#define     BUTTON_up             BIT1      // Switch up
#define     BUTTON_left           BIT2      // Switch left
#define     BUTTON_right          BIT3      // Switch right
#define     BUTTON_mode           BIT4      // Menu
#define     BUTTON_alarm          BIT5      // Alarm off

#define     BUTTON_last           BIT5
#define     PWR_UP                BIT7      // 5 Volt ready

#define     BTN_PRESS_SHORT       BIT0
#define     BTN_PRESS_LONG        BIT1
#define     BTN_PRESS_INTER       BIT2
#define     BTN_PRESS_DOUBL       BIT3
#define     BTN_PRESS_INTER_FIRST BIT7

#define     DISPLAY_OUT           P2OUT
#define     DISPLAY_DIR           P2DIR
#define     DISPLAY_IN            P2IN
#define     BCD_0                 BIT0
#define     BCD_1                 BIT1
#define     BCD_2                 BIT2
#define     BCD_3                 BIT3
#define     DIGT_1                BIT4
#define     DIGT_2                BIT5
#define     DIGT_3                BIT6
#define     DIGT_4                BIT7

#define     DIGT_PNT1             BIT1
#define     DIGT_PNT2             BIT0
#define     DIGT_PNT3             BIT3
#define     DIGT_PNT4             BIT2
#define     SEC_PNT               BIT4
#define     MINUS_PNT             BIT5
#define     SEC_PNT_RESULT        BIT6
#define     MINUS_PNT_RESULT      BIT7

#define     SERIAL_SEL            P3SEL
#define     TXD                   BIT3      // TXD on P3.3
#define     RXD                   BIT4      // RXD on P3.4

#define     CONTROL_OUT           P4OUT
#define     CONTROL_DIR           P4DIR
#define     CONTROL_IN            P4IN
#define     CONTROL_DS            P4DS
#define     TURNON_OPA            BIT0      // switch the op-amp on
#define     TURNON_RELAY          BIT1      // switch the relay on
#define     AL1                   BIT2      // Alarm Piezo

#define     CRYSTAL_SEL           P5SEL
#define     XT2IN                 BIT2
#define     XT2OUT                BIT3
#define     XIN                   BIT4
#define     XOUT                  BIT5

#define     VOLTMETER_SEL         P6SEL
#define     U_BAT                 BIT0
#define     U_TEMP                BIT1
#define     U_LIGTH               BIT2

#define     SIGNALS_OUT           P7OUT
#define     SIGNALS_DIR           P7DIR
#define     SIGNALS_IN            P7IN
#define     SIGNALS_DS            P7DS

#define     DARK                  BIT0      // Blanking Dunkeltastung
#define     LED_OSCI_FAULT        BIT1      // LED Oszillator 4MHz schwingt nicht
#define     LED_SEC               BIT2      // LED Sekunden
#define     LED_MINUS             BIT3      // LED für ein negatives Ergebnis
#define     LED_DP                BIT7      // LED decimal point

// ADC

#define CALADC12_15V_30C  *((uint16_t *)0x1A1A)   // Temperature Sensor Calibration-30 C
                                                      //See device datasheet for TLV table memory mapping
#define CALADC12_15V_85C  *((uint16_t *)0x1A1C)   // Temperature Sensor Calibration-85 C

#define CORREC_OFFSET_PT100     3050

#define CALADC12_25V_PT100_00C  398               // Temperature sensor PT100 calibration 0,0 C (100Ω)

#define CALADC12_25V_PT100_80C  1947

#define CALADC12_25V_BATT_1V5  632               // Battery Calibration 1,5V

#define CALADC12_25V_BATT_3V6  2948              // Battery Calibration 3,6V

// TYPEDEF & STRUCTs

// Variablen die "globale" Zusände steuern ----
// variables that control "global" states

enum EVE_con_typ
{
    normal = 0, // (hh:mm)
    view_sec_and_min,
    view_day_and_month,
    view_day_of_week,
    view_alarm_time1,
    view_alarm_time2,
    view_alarm_time3,
    view_alarm_time4,
    view_alarm_time5,
    view_year,
    view_temp_cpu,
    view_temp_out,
    view_bright,
    view_batt,
    view_rtc_corr,
    change_sec,
    change_min,
    change_h,
    change_d,
    change_monts,
    change_year,
    change_arlarm,
    change_arl_time,
    change_a_mon,
    change_a_tue,
    change_a_wend,
    change_a_thu,
    change_a_fri,
    change_a_san,
    change_a_son,
    change_rtc_corr
} ene_con_gr;

enum ADC_mesure_typ
{
    measurement_temp_cpu,
    measurement_batt,
    measurement_temp_out,
    measurement_bright
};

enum ADC_Work
{
    status_it_is_nothing = 0,
    status_adc_ready,
    status_adc_pwr_go_on,
    measure_batt_f_contr,
    measure_batt_f_disp,
    measure_bright_f_contr,
    measure_bright_f_disp,
    measure_temp_cpu_f_disp,
    measure_temp_out_f_disp,
};

enum FLASH_write_data
{
    write_ver,
    write_date,
    write_RTC_correction,
    write_TEMP_correction,
    write_BATT_correction,
    write_ALARM1,
    write_ALARM2,
    write_ALARM3,
    write_ALARM4,
    write_ALARM5,
};
#define     BATT_F_CONTR_READY    BIT0
#define     BATT_F_DISP_READY     BIT1
#define     BRIGHT_F_CONTR_READY  BIT2
#define     BRIGHT_F_DISP_READY   BIT3
#define     TEMP_CPU_F_DISP_READY BIT4
#define     TEMP_OUT_F_DISP_READY BIT5
#define     FIRST_ADC_DISPLAY     BIT7

#define     ALARM_BEEP            BIT0
#define     ALARM_LEV01           BIT1
#define     ALARM_LEV02           BIT2
#define     ALARM_LEV03           BIT3
#define     ALARM_LEV04           BIT4
#define     ALARM_ISR_FLAG        BIT6
#define     ALARM_STOP            BIT7

#define     BEEPER_ON             CONTROL_OUT &= ~AL1
#define     BEEPER_OFF            CONTROL_OUT |= AL1

#define     MENU_STOP_COUNT       10    // in sec
#define     MENU_WHATEVER_FLAG     0
#define     MENU_STOP_FLAG         1

struct alarm_set {
    uint8_t alarm_days, alarm_min, alarm_hour, alarm_day, alarm_mounth;
};

enum MENU_layer
{
    time_date,
    measured_data,
    alarm_times,
    set_clock,
    set_alarm_clock,
    set_sensor_offsets,
};
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

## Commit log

2020-06-15 Upload other projectfiles
    [Aufstellung_Pins.ods]
2020-06-15 Changes for testing
    Changes for testing
    [Aufstellung_Pins.ods]
2020-06-15 3V3 V_regulator insert
2020-06-22 Replace INTs and first impl. ADC_scheduler
    [Aufstellung_Pins.ods]
2020-07-04 Implemetation of CPU-temperature output
2020-07-21 Work at connector pinlayout and groundmesh
    [Aufstellung_Pins.ods]
2020-07-30 impl decimalpoint & button fkt.
2020-09-01 first program flow chart
2020-09-05 Update pin layout to the front panel
    [Aufstellung_Pins.ods]
2020-09-06 new design disp.-connector
    [Aufstellung_Pins.ods]
2020-09-24 Imp. ADC-Log. and menuelog.
2020-10-04 circuit diagram almost finished
    [Aufstellung_Pins.ods]
2020-10-05 small changes to the circuit diagram
    Power
    measurement of voltage
2020-10-12 controlling ADC-power
2020-10-16 PCB Front ready (almost finished)
    [Digi_Uhr_Front.OBJ]
2020-10-28 Layout Mainboard
    [Aufstellung_Pins.ods]
2020-11-03 Mainboard Layout
    Problem with Goundplane
    [Digi_Uhr.ods]
2020-11-07 PCB is in produktion
2020-11-07 Dok. that the PCB is ready and in Produktion
2020-11-23 error correction
    insert a description, what is wrong
2020-12-09 correction of the assignment
    [Aufstellung_Pins.ods]
2021-01-11 Timing Ver1.0 ready
    calibration not perfect
    first test of KiCad
    [Aufstellung_Pins.ods, KonstantStromQuelle.kicad_pcb, KonstantStromQuelle.sch]
2021-01-12 impl. Switch
2021-01-12 Conflict ods-file
    [Aufstellung_Pins_2.ods]
2021-01-12 the conflict-file is newer
    [Aufstellung_Pins.ods]
2021-02-14 Beeper Impl.
    [Aufstellung_Pins.ods, Aufstellung_Pins_2.ods, KonstantStromQuelle.sch]
2021-04-04 Strart FlashWrite and PCB Ver.1.1 is ready
    [KonstantStromQuelle-B_Cu.gbr, KonstantStromQuelle-B_Mask.gbr, KonstantStromQuelle-B_Paste.gbr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]
